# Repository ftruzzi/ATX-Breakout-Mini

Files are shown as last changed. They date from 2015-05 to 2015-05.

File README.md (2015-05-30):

ATX Breakout Board
=================

Eagle files for my ATX Breakout Board (v1, with USB support using a TPS2513 and voltage control with a LM317). Based on the Dangerous Prototypes' idea.

## New version (v1.2) ##

<p align="center">
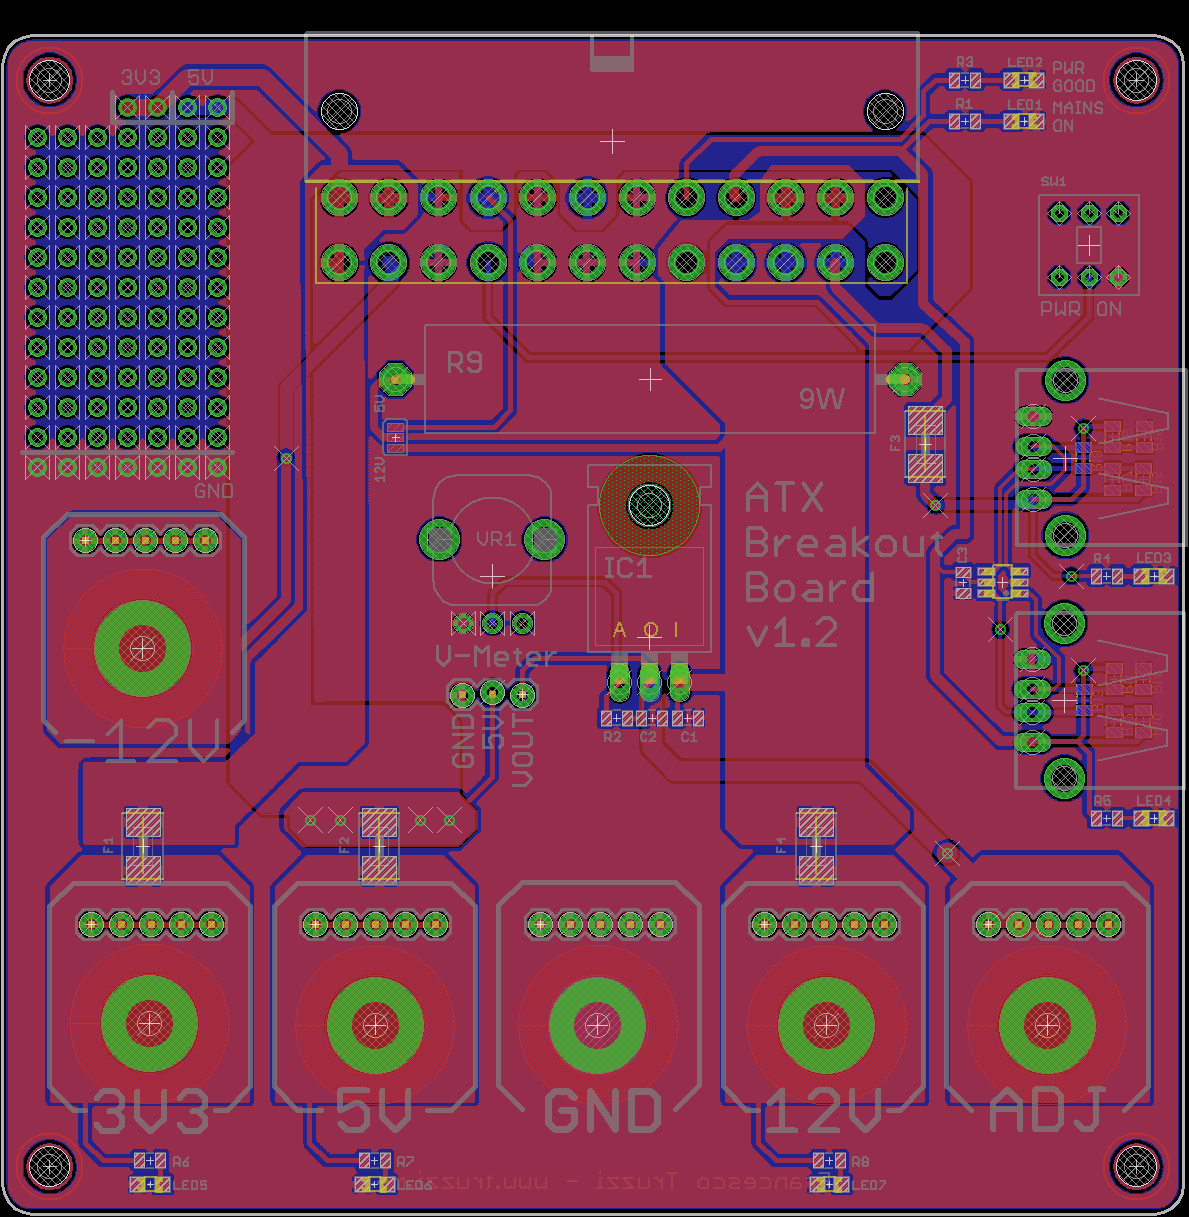
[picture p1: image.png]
  
</p>

Just finished updating the board. BOM updates and post blogs will follow. I'm also printing a second batch (20-30 PCBs) soon.

Changes and additions:

*   Thickened many traces, **removed pin headers** in the middle of the board and **added one behind each binding post** (up to 5 output pins per voltage line, with no risk of burning any traces).
*   **Added resistors to the USB ports (on the back of the board).** You may want to use them for USB identification, as they are cheaper and easier to find than the TPS2513. Adafruit link for more info: https://learn.adafruit.com/minty-boost/icharging
*   Moved LM317 so that you can mount it horizontally + used a footprint with longpads, should you want to solder wires to an external voltage reg + heatsink.
*   **Prototyping area added** at the top left of the board. Not sure if it will ever come useful, but I had some empty space there. You have easy access to the 3V3 and 5V lines.
*   Moved/rearranged several parts (pot, switch, LEDs) in order to draw shorter and cleaner traces.

##Features

*   **24-pin ATX** connector.
*   Voltage lines are all broken out individually on **binding posts**.
*   **LM317-based voltage regulator**. Using a 300 ohm resistor and a 2K ohm potentiometer, voltage range is 1.25-9V.
*   **2 USB ports **based on the TPS2513 from Texas Instruments. They can automatically detect what device is connected and adjust resistance on D+ and D- lines as needed. This means **full compatibility and maximum charging speed on both Apple and Android devices**. One of them is connected to 5v_STDBY, so that it works even when the PSU is off.
*   Pretty much everything can be **fused**. I left -12V out because it can only carry low amounts of current on most PSUs (mine is 500mA maximum).
*   **Breadboard pin headers** so that voltage lines can be connected to a breadboard using jumper cables.
*   **Voltmeter** headers in order to know the LM317 output voltage.
*   There is room for a **9W power resistor** is your PSU needs it to stabilize output voltages. You can connect it either to the 5v rail or to the 12v one by jumpering the corresponding pads.
*   **Status LEDs** on fused lines and USBs so you can check if everything works fine.
*   Screw holes for standoffs.

More details and pictures on my blog: http://b.truzzi.me/building-a-better-breakout-board-for-atx-psus-2

Suggestions and feedback are very welcome!

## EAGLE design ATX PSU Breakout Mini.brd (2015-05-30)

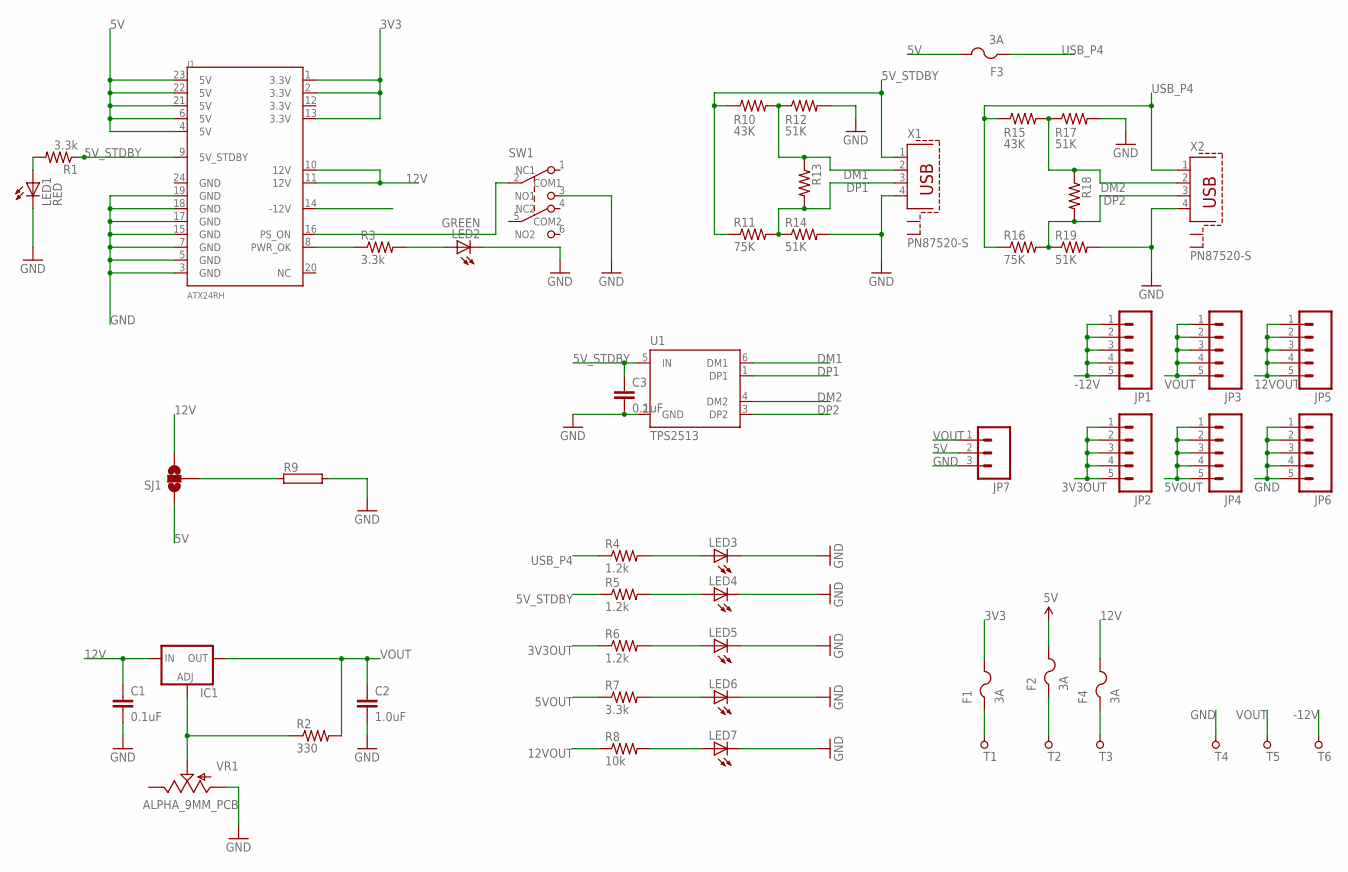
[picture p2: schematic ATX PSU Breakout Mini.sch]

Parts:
C1, C3: 0.1uF; 0805
C2: 1.0uF; 0805
F1, F2, F3, F4: 3A; 1812
IC1: LM317TL; 317TL
J1: ATX24RH; ATX24_RIGHT_ANGLE
JP1, JP2, JP3, JP4, JP5, JP6: M05PTH; 1X05
JP7: M03LOCK; 1X03_LOCK
LED1: RED; CHIPLED_0805
LED2: GREEN; CHIPLED_0805
LED3, LED4, LED5, LED6, LED7: LEDCHIPLED_0805; CHIPLED_0805
R1, R3, R7: 3.3k; 0805
R2: 330; 0805
R4, R5, R6: 1.2k; 0805
R8: 10k; 0805
R9: RKH214-8; KH214-8
R10, R15: 43K; 0805
R11, R16: 75K; 0805
R12, R14, R17, R19: 51K; 0805
R13, R18: RESISTOR0805-RES; 0805
SJ1: SOLDERJUMPER_2WAYS; SJ_3
SW1: SW_PUSH_DPDT; SW_PUSH_BUTTON_MINI
T1: 3V3; PAD_ROUND_4.1MM
T2: 5V; PAD_ROUND_4.1MM
T3: 12V; PAD_ROUND_4.1MM
T4: GND; PAD_ROUND_4.1MM
T5: ADJ; PAD_ROUND_4.1MM
T6: -12V; PAD_ROUND_4.1MM
U1: TPS2513; SOT23-6
VR1: ALPHA_9MM_PCB
X1, X2: PN87520-S

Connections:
3V3: F1.2, J1.1 (3.3V), J1.2 (3.3V), J1.13 (3.3V)
3V3OUT: F1.1, JP2.1, JP2.2, JP2.3, JP2.4, JP2.5, R6.1, T1.P
5V: F2.2, F3.2, J1.4 (5V), J1.6 (5V), J1.21 (5V), J1.22 (5V), J1.23 (5V), JP7.2, SJ1.1
5VOUT: F2.1, JP4.1, JP4.2, JP4.3, JP4.4, JP4.5, R7.1, T2.P
5V_STDBY: C3.1, J1.9 (5V_STDBY), R1.1, R5.1, R10.1, R11.1, U1.5 (IN), X1.1
12V: C1.1, F4.2, IC1.3 (IN), J1.10 (12V), J1.11 (12V), SJ1.3
12VOUT: F4.1, JP5.1, JP5.2, JP5.3, JP5.4, JP5.5, R8.1, T3.P
-12V: J1.14 (-12V), JP1.1, JP1.2, JP1.3, JP1.4, JP1.5, T6.P
DM1: R10.2, R12.1, R13.1, U1.6 (DM1), X1.2
DM2: R15.2, R17.1, R18.1, U1.4 (DM2), X2.2
DP1: R11.2, R13.2, R14.1, U1.1 (DP1), X1.3
DP2: R16.2, R18.2, R19.1, U1.3 (DP2), X2.3
GND: C1.2, C2.2, C3.2, J1.3 (GND), J1.5 (GND), J1.7 (GND), J1.15 (GND), J1.17 (GND), J1.18 (GND), J1.19 (GND), JP6.1, JP6.2, JP6.3, JP6.4, JP6.5, JP7.3, LED1.C, LED2.C, LED3.C, LED4.C, LED5.C, LED6.C, LED7.C, R9.2, R12.2, R14.2, R17.2, R19.2, SW1.3 (NO1), T4.P, U1.2 (GND), VR1.1 (A), X1.4, X2.4
unnamed: J1.8 (PWR_OK), R3.1
unnamed: LED2.A, R3.2
unnamed: R9.1, SJ1.2
unnamed: IC1.1 (ADJ), R2.1, VR1.2 (S)
unnamed: J1.16 (PS_ON), SW1.2 (COM1)
unnamed: LED1.A, R1.2
unnamed: LED4.A, R5.2
unnamed: LED3.A, R4.2
unnamed: LED5.A, R6.2
unnamed: LED6.A, R7.2
unnamed: LED7.A, R8.2
USB_P4: F3.1, R4.1, R15.1, R16.1, X2.1
VOUT: C2.1, IC1.2 (OUT), JP3.1, JP3.2, JP3.3, JP3.4, JP3.5, JP7.1, R2.2, T5.P

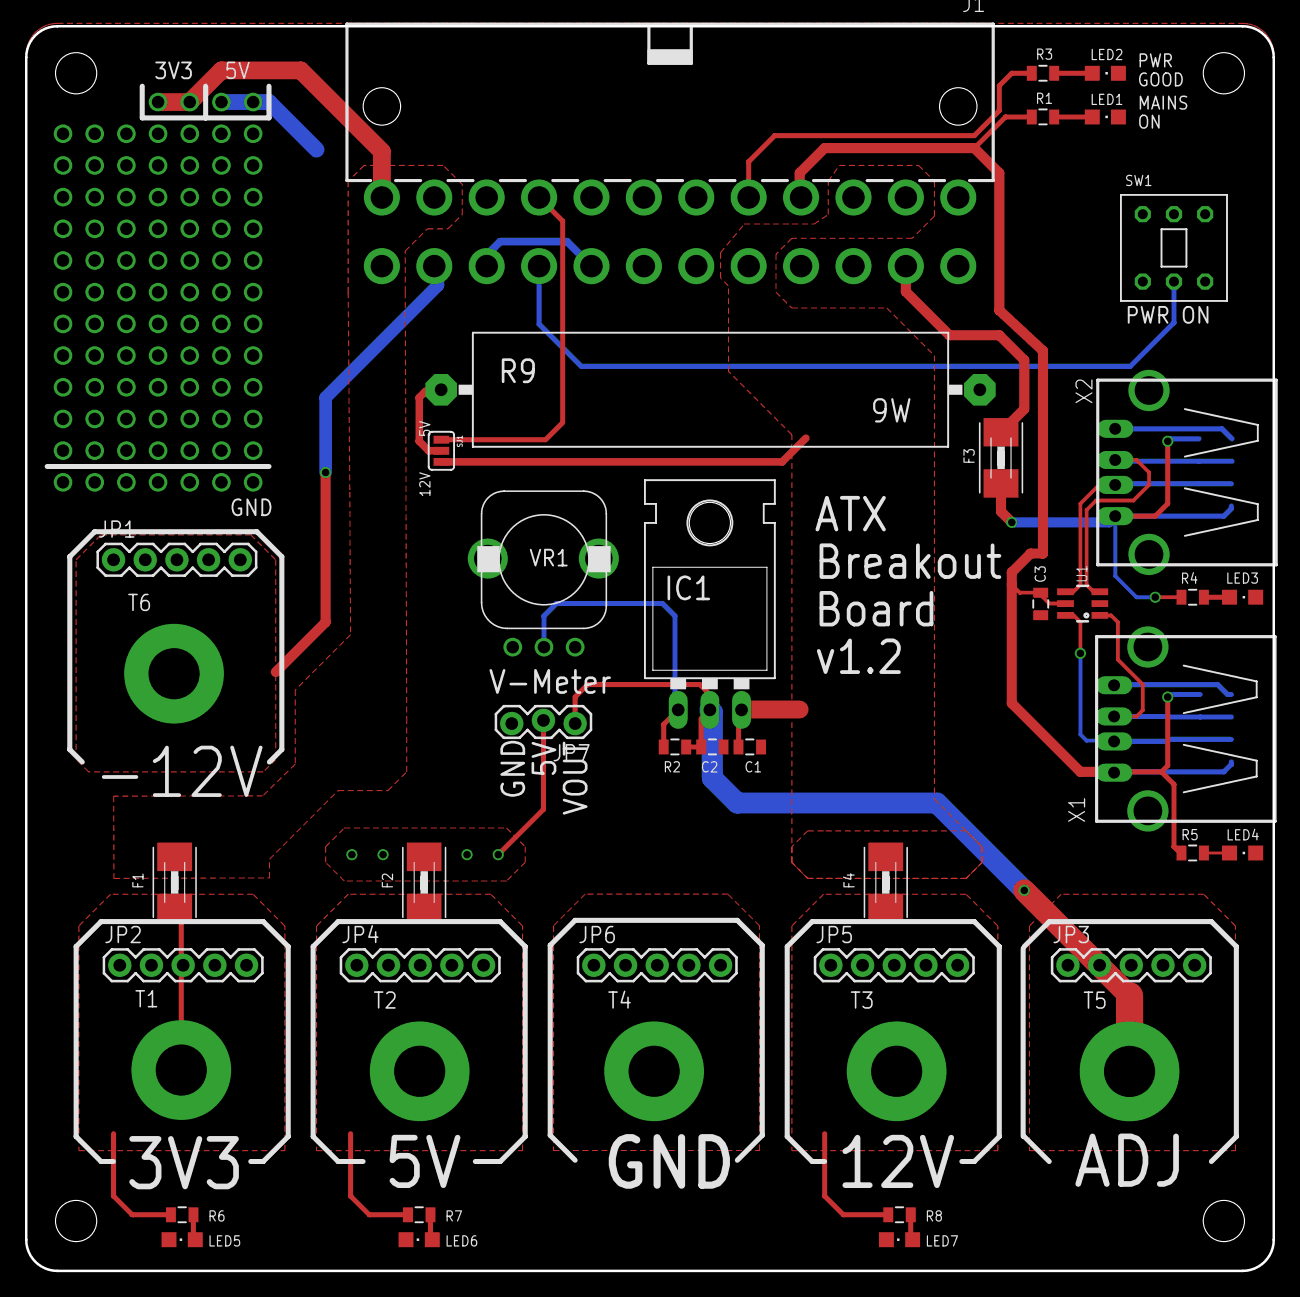
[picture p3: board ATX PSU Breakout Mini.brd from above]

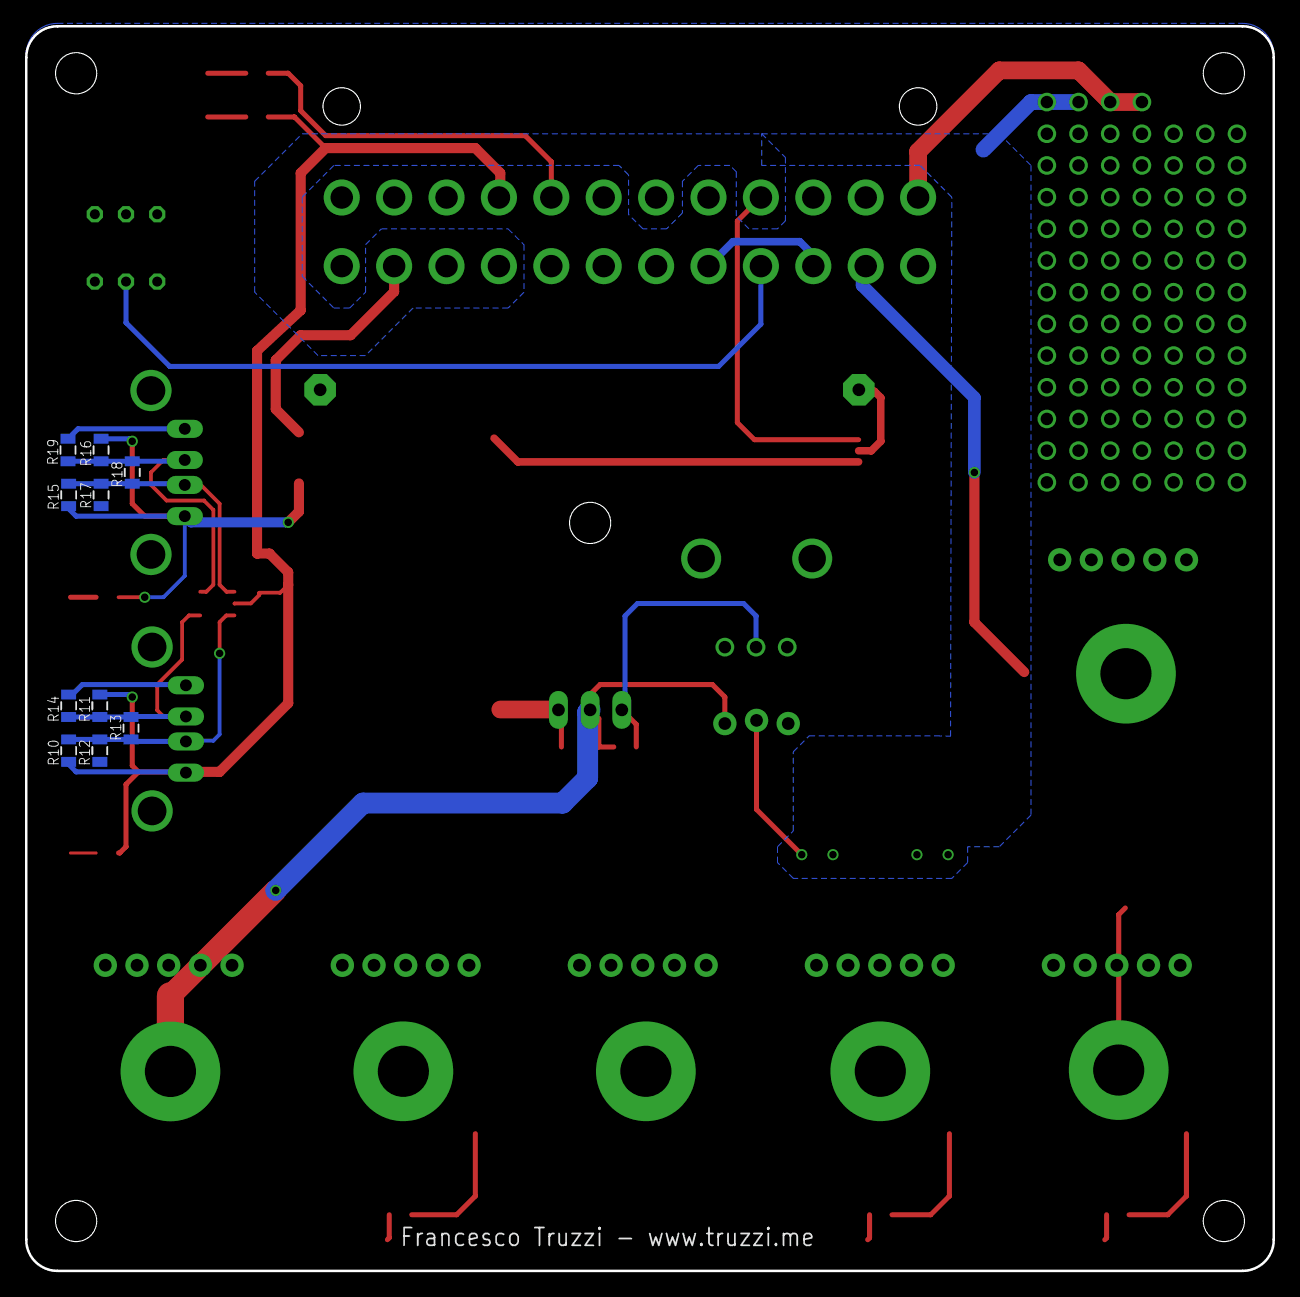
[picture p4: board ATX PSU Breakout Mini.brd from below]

Board: 2 copper layers, 100.0 x 99.8 mm, 58 parts (10 on the bottom side), 26 nets.

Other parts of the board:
U$1, U$2, U$3, U$4: STAND-OFF

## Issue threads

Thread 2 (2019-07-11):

Expose all the pins

LinoBarreca, 2019-07-11:
Hi. The idea is nice but it still has a fault:
Suppose I want to pilot this through a microcontroller let's say a UNO.
It would be VERY nice to connect it directly with ATX pins to trigger some actions.
(ie: remote on by grounding the pin, power ready, remote voltages monitoring and so on)
for the next board revision you should add a female connector for each of the atx pins (without any electronics of any sort)...an array...or a board hole in which one can solder it (male or female as needed) . in that connector you could put a jumper cable to connect it to arduino (or other electronics) to monitor/pilot the board and the PSU.

LinoBarreca, 2019-07-11:
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
something like this, for example.

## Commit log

2014-11-28 first version, eagle files
    [ATX PSU Breakout Mini.brd, ATX PSU Breakout Mini.sch]
2015-02-06 Fixes and additions.
    Thickened all traces, added resistors to the USB ports (you can use them
    instead of the TPS2513)
    [ATX PSU Breakout Mini.brd, ATX PSU Breakout Mini.sch]
2015-05-30 New version (v1.2)
    Fixed bugs, rearranged traces and components, added pin headers, USB
    resistors and prototyping area.
    [ATX PSU Breakout Mini.brd, ATX PSU Breakout Mini.sch]

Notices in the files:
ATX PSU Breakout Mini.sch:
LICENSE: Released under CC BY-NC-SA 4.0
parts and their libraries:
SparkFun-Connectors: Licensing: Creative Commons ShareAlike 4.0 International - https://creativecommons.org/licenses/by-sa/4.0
